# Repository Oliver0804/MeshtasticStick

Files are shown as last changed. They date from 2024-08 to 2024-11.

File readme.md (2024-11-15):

# MeshtasticStick
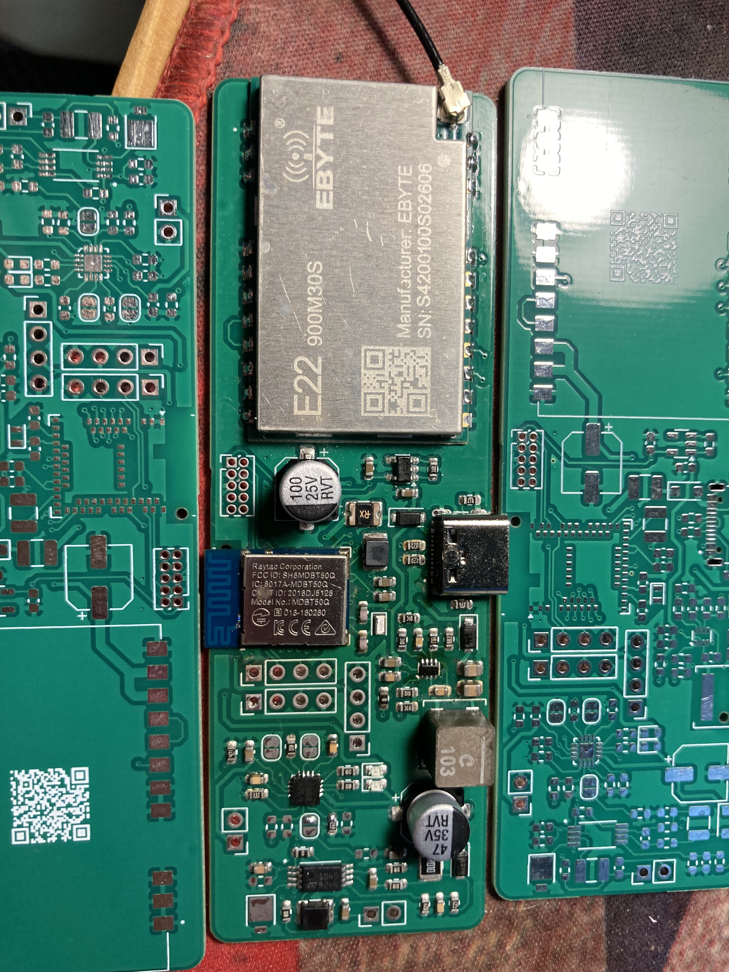
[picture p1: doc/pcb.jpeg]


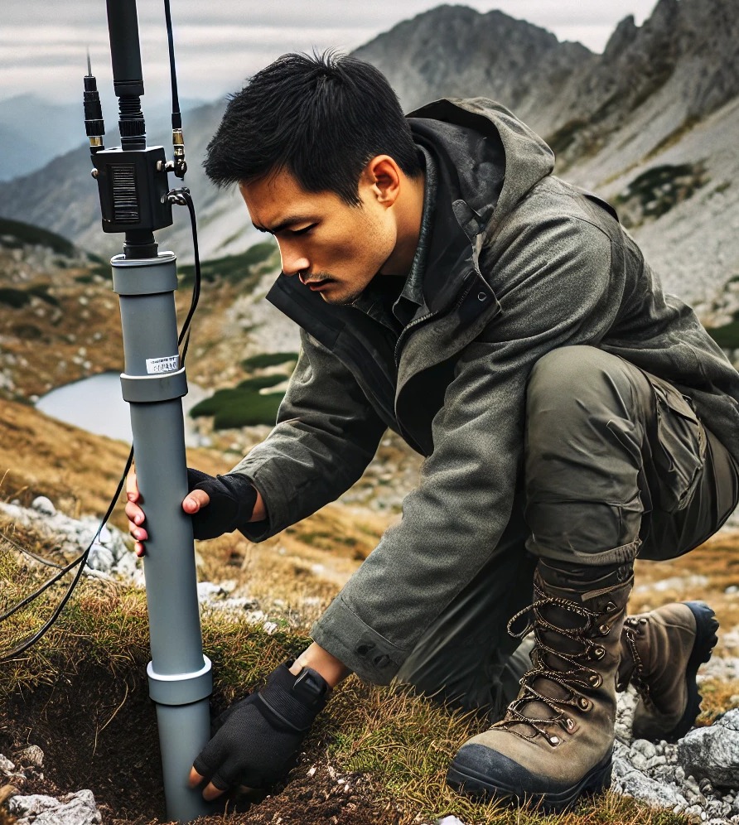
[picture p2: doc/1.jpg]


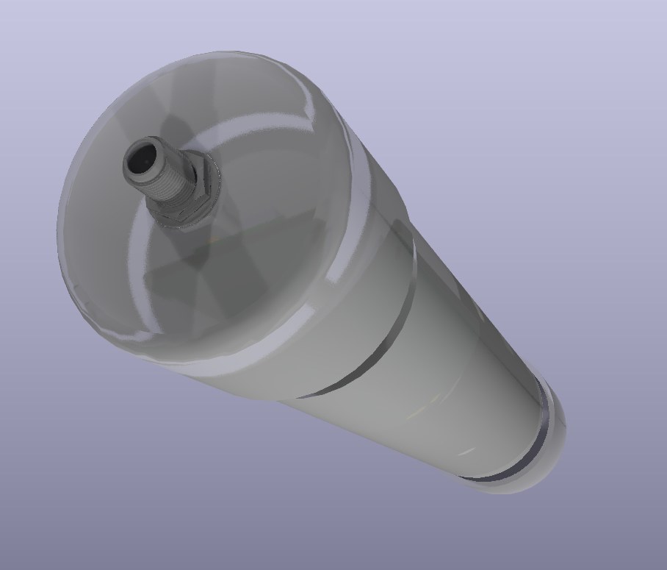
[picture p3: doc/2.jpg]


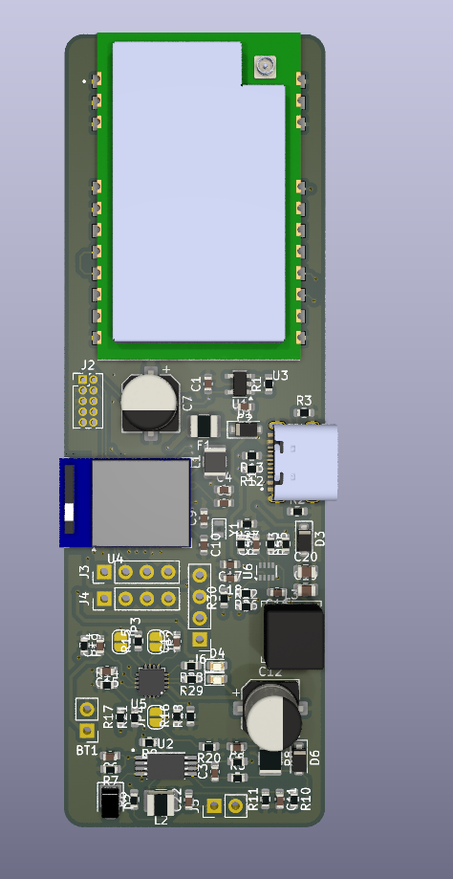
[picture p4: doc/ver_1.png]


1. 支持太陽能（0.3V~5.5V）
2. 支持寬壓輸入（4.5V~28V）
3. TypeC 供電(輸入最少5V/1.5A)，如無充電狀況下約0.8A
4. NRF52 不支持WI-FI
5. 預留I2C,GPS接口(GPS可使用Jumper切換電壓3v3/5v0)

# 原理圖
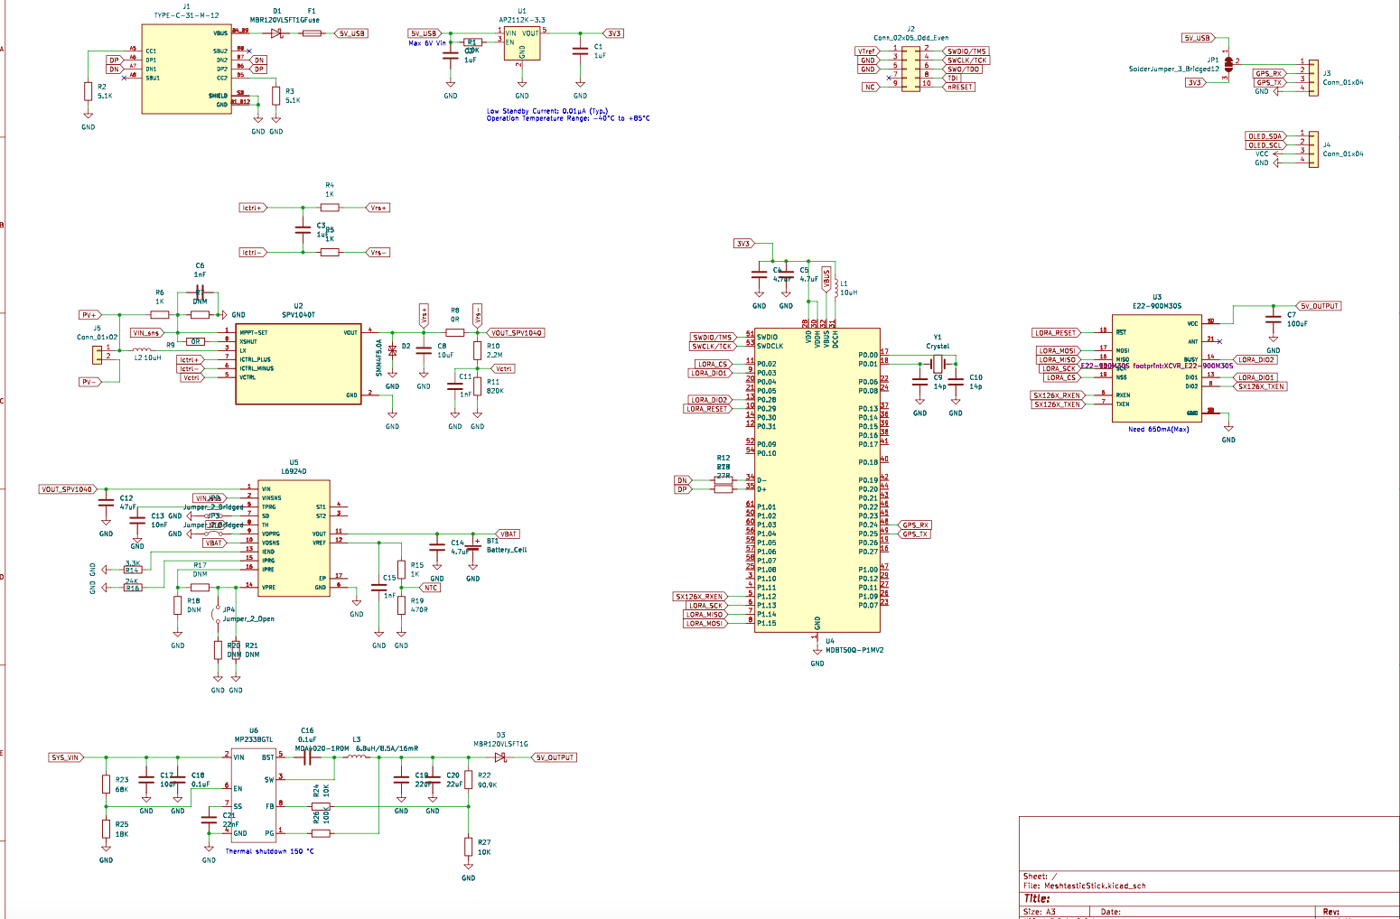
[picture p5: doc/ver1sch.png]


# 主要零件
1. MDBT50Q-P1MV2
描述: 這是由Raytac Corporation生產的一款BLE模塊，基於Nordic Semiconductor的nRF52840晶片。此模塊支持Bluetooth 5.1規範，具有低功耗藍牙(BLE)功能。
優勢: 具有較大的傳輸範圍、高數據傳輸速率和低能耗。支持多種無線通訊協議，包括藍牙、ANT和2.4 GHz射頻。此外，內建32位ARM Cortex-M4 CPU，具有豐富的GPIO和接口，適合複雜的物聯網(IoT)應用。

2. SPV1040（voltage range from 0.3 V to 5.5 V）
描述: SPV1040是STMicroelectronics的一款高效率太陽能充電控制器，適用於低功耗應用和可攜式太陽能系統。
優勢: 能夠在廣泛的太陽照射條件下有效提高能量收集效率，支持最大功率點追蹤(MPPT)技術，以最大化太陽能板的能量輸出。此IC具有過載保護和熱保護功能，能確保系統的穩定與安全。

3. L6924 (取代LT4056系列)
描述: L6924是一款用於單節鋰離子或鋰聚合物電池的充電管理IC，由STMicroelectronics製造。
優勢: 這個充電器支持調整充電電流和電壓，以適應不同電池的需求。它包括內部功率晶體管和電流感測功能，無需外部許多元件，非常適合便攜式設備。

4. MP2338 (4.5V to 28V Operating Input Range)
描述: MP2338是由MPS公司生產的一款同步降壓轉換器，用於將更高的電壓轉換為更低的電壓，同時提供高效率和優異的負載調節。
優勢: 它具有高達95%的轉換效率，非常適合需要高效能轉換的應用。此外，其具有緊湊的尺寸和低靜態功耗，非常適合電池供電的系統。

5. E22-900M30/33 1W LORA
描述: Ebyte製造的E22-900M30/33是一款高功率LoRa模塊，工作在900 MHz頻段，提供長距離無線通信。
優勢: 此模塊的最大發射功率達到1瓦特，能夠實現極遠的通信距離。支持LoRa和FSK調制，具有良好的抗干擾性能和低功耗特性。此外，模塊的配置靈活，支持多種工作模式，非常適合需要遠距離數據傳輸的物聯網應用。

# TODO
- [ ] 確認SPV1040工作狀態
- [ ] L6924 ST1,ST2確認設計方式
- [ ] 確認4.2v供電

# ref

- 太陽能設計文件
https://static5.arrow.com/pdfs/2011/10/8/19/12/15/660/st_/auto/steval-isv012v1_schematic.pdf

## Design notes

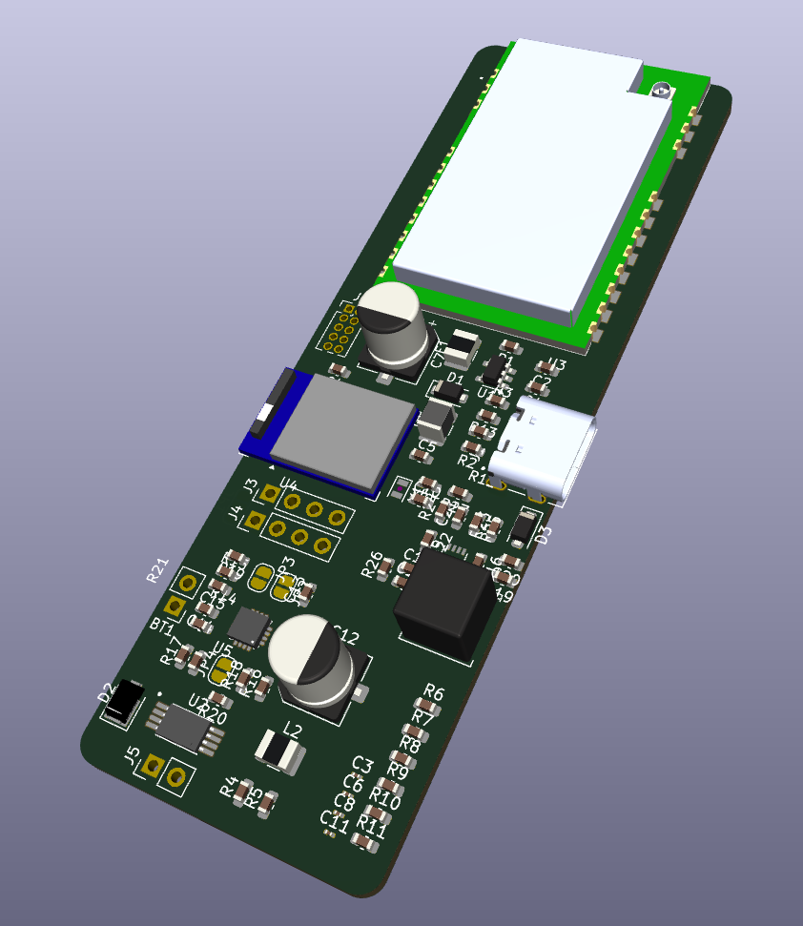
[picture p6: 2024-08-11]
doc/ver13d.png

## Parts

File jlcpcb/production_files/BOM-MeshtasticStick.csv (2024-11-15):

Comment | Designator | Footprint | LCSC | Quantity
68K | R23 | R_0603_1608Metric | C12036 | 1
0.1uF | C16,C18,C6 | C_0603_1608Metric | C14663 | 3
1uF | C1,C2,C3 | C_0603_1608Metric | C15849 | 3
1nF | C11,C15 | C_0603_1608Metric | C1588 | 2
100K | R26 | R_0603_1608Metric | C17900 | 1
4.7uF | C14,C4,C5 | C_0603_1608Metric | C19666 | 3
10uF | C17,C22,C8 | C_0603_1608Metric | C19702 | 3
SMM4F5.0A | D2 | D_SMP_DO-220AA | C1976670 | 1
Fuse | F1 | Fuse_1210_3225Metric | C20806 | 1
22nF | C21 | C_0603_1608Metric | C21122 | 1
0R | R30,R9 | R_0603_1608Metric | C21189 | 2
1K | R15,R28,R29,R4,R5,R6 | R_0603_1608Metric | C21190 | 6
MBR120VLSFT1G | D1,D3,D6 | D_SOD-123F | C223608 | 3
LED | D4,D5 | LED_0603_1608Metric | C2286 | 2
2.2M | R10 | R_0603_1608Metric | C22938 | 1
3.3K | R14 | R_0603_1608Metric | C22978 | 1
90.9K | R22 | R_0603_1608Metric | C23129 | 1
470R | R19 | R_0603_1608Metric | C23179 | 1
5.1K | R2,R3 | R_0603_1608Metric | C23186 | 2
820K | R11 | R_0603_1608Metric | C23252 | 1
24K | R16 | R_0603_1608Metric | C23352 | 1
27R | R12,R13 | R_0603_1608Metric | C25190 | 2
10K | R1,R24,R27 | R_0603_1608Metric | C25804 | 3
18K | R25 | R_0603_1608Metric | C25810 | 1
AP2112K-3.3 | U1 | SOT-23-5 | C3021085 | 1
100uF | C7 | CP_Elec_6.3x7.7 | C3338 | 1
47uF | C12 | CP_Elec_6.3x7.7 | C3344 | 1
14p | C10,C9 | C_0603_1608Metric | C38523 | 2
22uF | C19,C20 | C_0805_2012Metric | C45783 | 2
10nF | C13 | C_0603_1608Metric | C57112 | 1
MP2338GTL | U6 | SOT-583-8 | C7210174 | 1
10uH | L1,L2 | L_1210_3225Metric | C86073 | 2
Crystal | Y1 | Crystal_SMD_2012-2Pin_2.0x1.2mm | C90943 | 1
TYPE-C-31-M-12 | J1 | HRO_TYPE-C-31-M-12 |  | 1
DNM | R20 | R_0603_1608Metric |  | 1
MDA4020-1R0M 6.8uH/8.5A/16mR | L3 | L_Coilcraft_XAL6060-XXX |  | 1
10mR | R8 | R_1210_3225Metric |  | 1
Conn_01x04 | J4 | PinHeader_1x04_P2.54mm_Vertical |  | 1
Conn_02x05_Odd_Even | J2 | PinHeader_2x05_P1.27mm_Vertical |  | 1
DNM | R18 | R_0603_1608Metric |  | 1
DNM | R21 | R_0603_1608Metric |  | 1
L6924D | U5 | QFN50P300X300X100-17N |  | 1
E22-900M30S | U3 | XCVR_E22-900M30S |  | 1
DNM | R17 | R_0603_1608Metric |  | 1
Conn_01x04 | J3 | PinHeader_1x04_P2.54mm_Vertical |  | 1
SPV1040T | U2 | SOP65P640X120-8N |  | 1
Jumper_2_Bridged | JP2 | SolderJumper-2_P1.3mm_Bridged2Bar_RoundedPad1.0x1.5mm |  | 1
Conn_01x04 | J6 | PinHeader_1x04_P2.54mm_Vertical |  | 1
Jumper_2_Bridged | JP3 | SolderJumper-2_P1.3mm_Bridged2Bar_RoundedPad1.0x1.5mm |  | 1
Conn_01x02 | J5 | PinHeader_1x02_P2.54mm_Vertical |  | 1
MDBT50Q-P1MV2 | U4 | Raytac_MDBT50Q |  | 1
Battery_Cell | BT1 | PinHeader_1x02_P2.54mm_Vertical |  | 1
Jumper_2_Open | JP4 | SolderJumper-2_P1.3mm_Open_RoundedPad1.0x1.5mm |  | 1
DNM | R7 | R_0603_1608Metric |  | 1

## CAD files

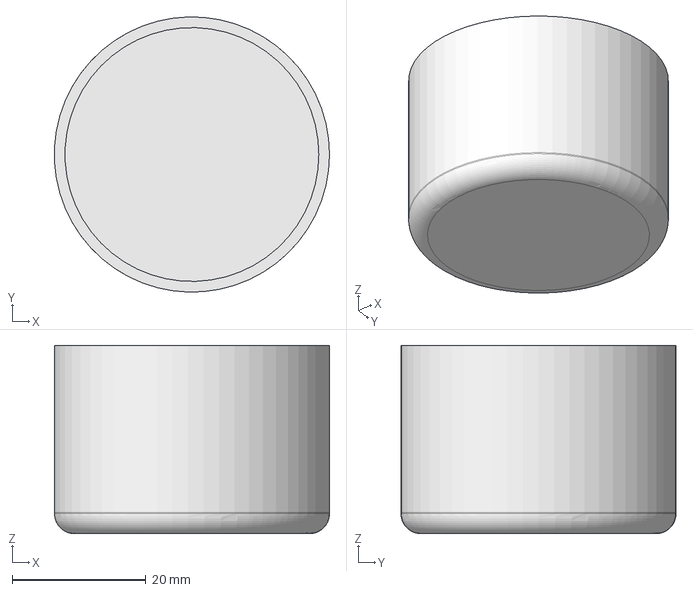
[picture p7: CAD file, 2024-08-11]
Case-PVC蓋子.step
41.2 x 41.2 x 28.2 mm

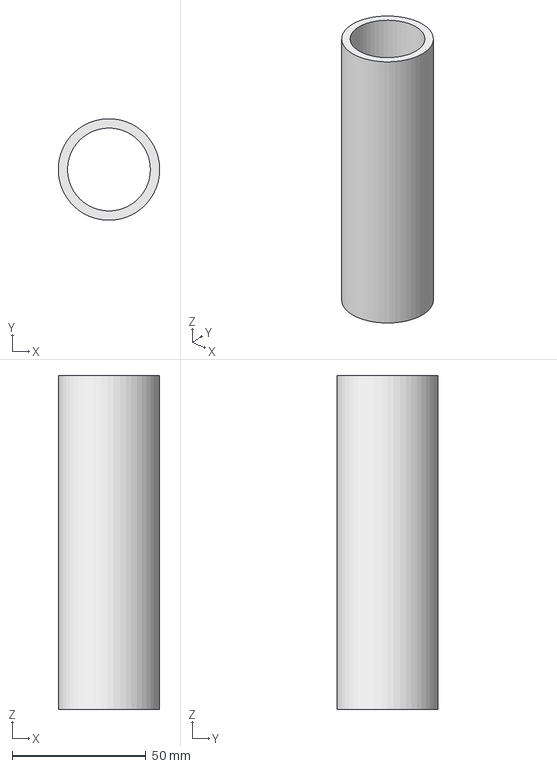
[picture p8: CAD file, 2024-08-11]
Case-PVC.step
38.0 x 38.0 x 125.0 mm

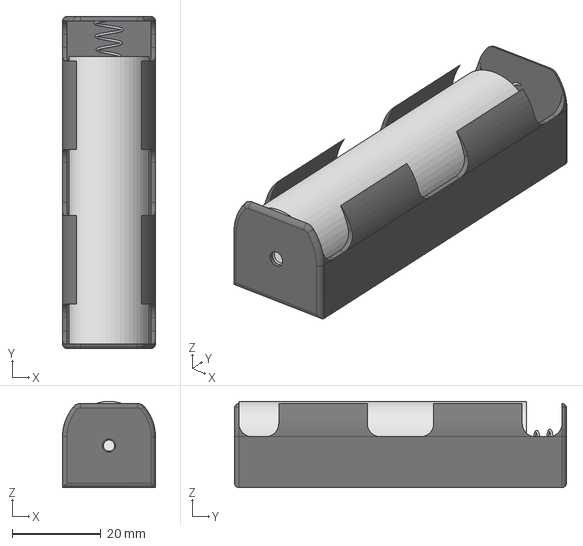
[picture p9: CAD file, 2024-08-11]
18650 Battery Holder v5.step
21.0 x 75.0 x 19.5 mm

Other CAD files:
Case.FCStd

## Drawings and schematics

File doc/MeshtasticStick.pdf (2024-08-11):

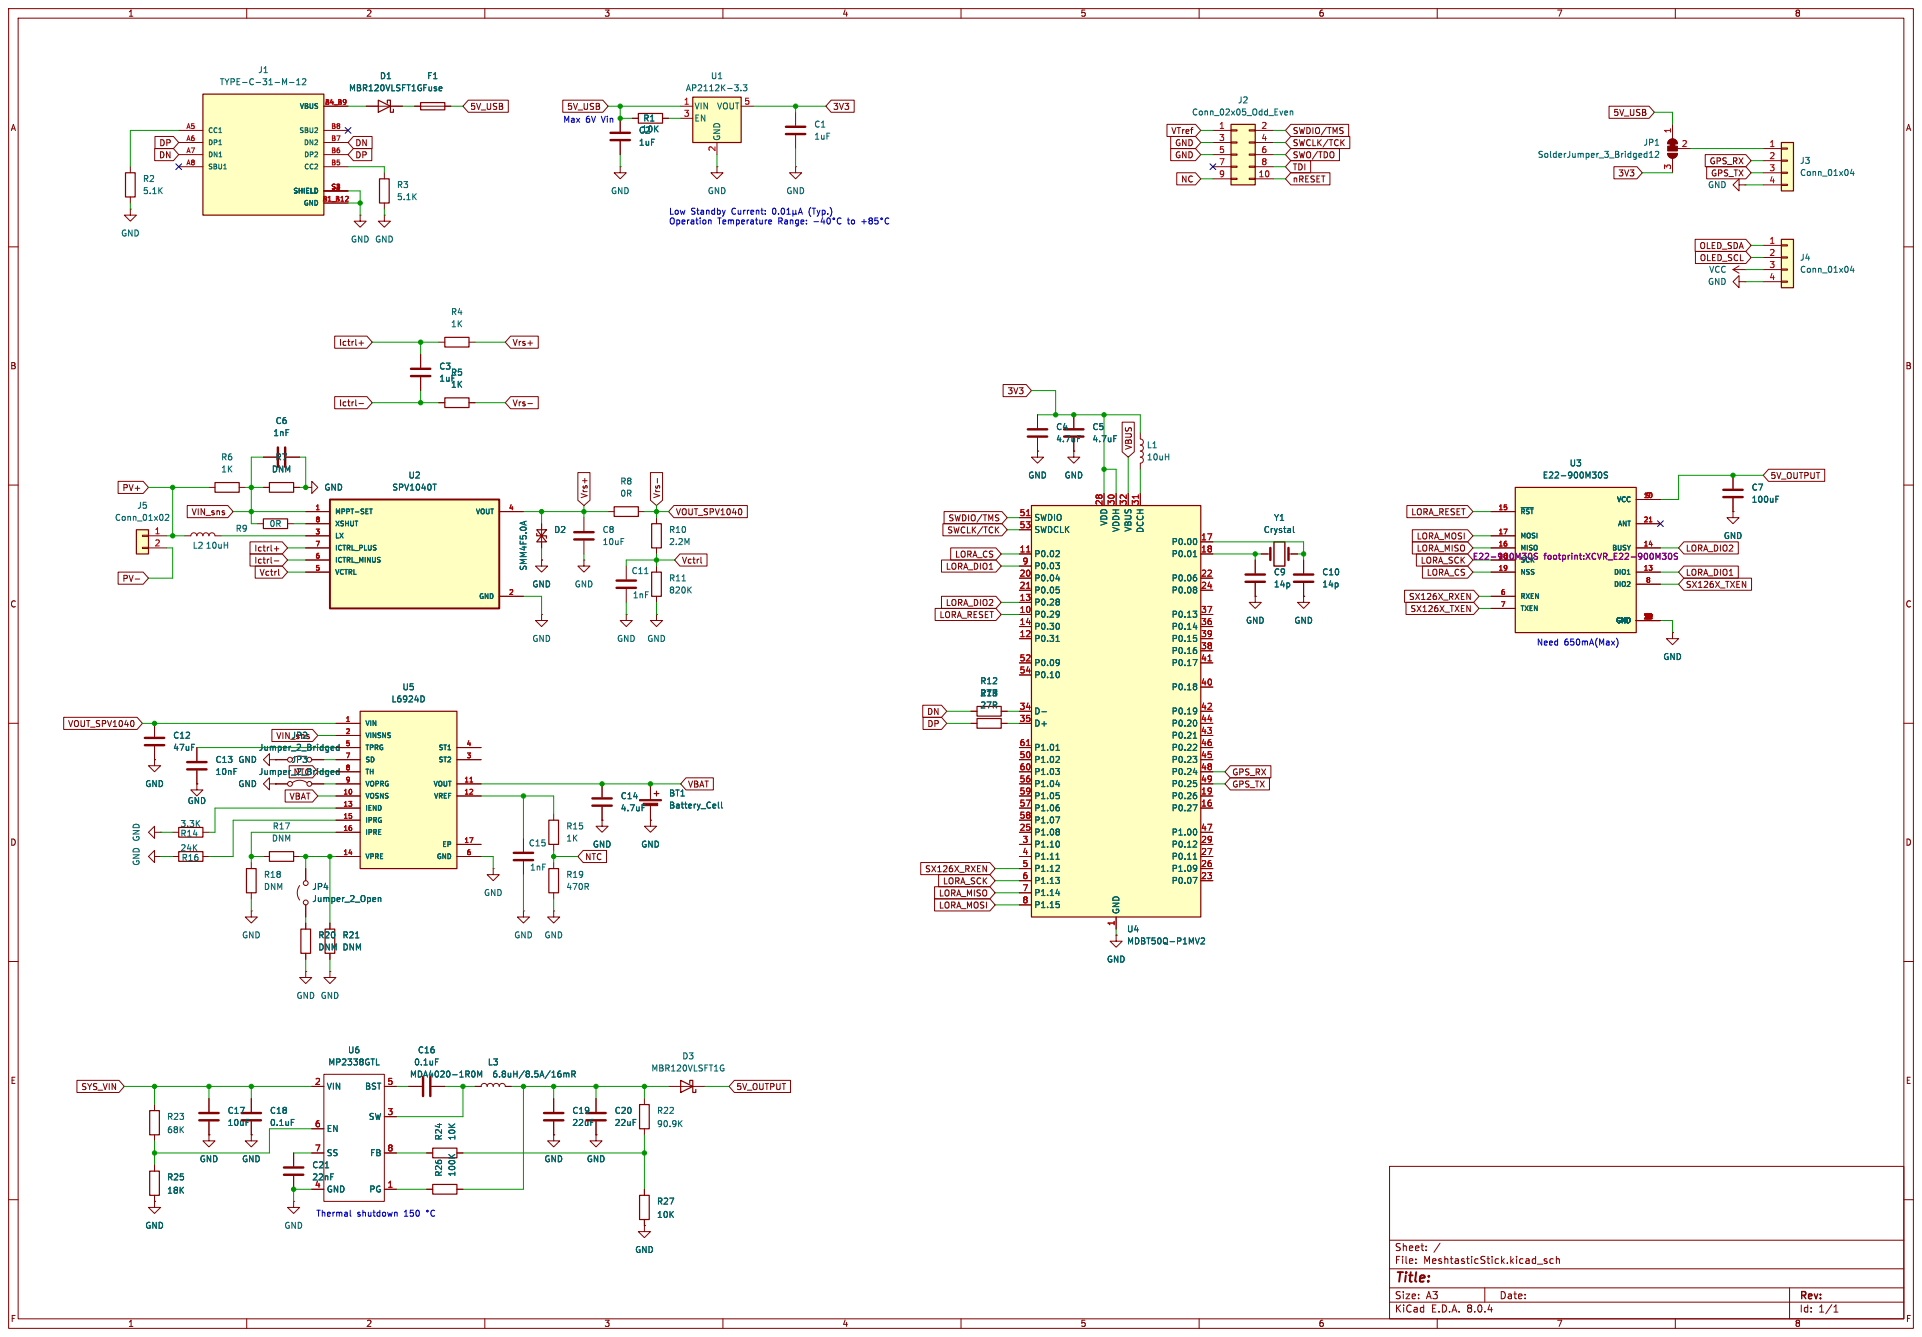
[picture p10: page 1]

Low Standby Current: þÿ0.01µA(Typ.)

1 P0.29 10 P0.02 11 P0.31 12 P0.28 13 P0.30 14 P0.27 16 P0.00 17 P0.01 18 P0.26 19 P0.04 20 P0.05 21 P0.06 22 P0.07 23 P0.08 24 P1.08 25 P1.09 26 P0.11 27 VDD 28 P0.12 29 P1.10 3 VDDH 30 DCCH 31 VBUS 32 D- 34 D+ 35 P0.14 36 P0.13 37 P0.16 38 P0.15 39 P1.11 4 P0.18 40 P0.17 41 P0.19 42 P0.21 43 P0.20 44 P0.23 45 P0.22 46 P1.00 47 P0.24 48 P0.25 49 P1.12 5 P1.02 50 SWDIO 51 P0.09 52 SWDCLK 53 P0.10 54 P1.04 56 P1.06 57 P1.07 58 P1.05 59 P1.13 6 P1.03 60 P1.01 61 P1.14 7 P1.15 8 P0.03 9 U4 MDBT50Q-P1MV2 GND

1 P0.29 10 P0.02 11 P0.31 12 P0.28 13 P0.30 14 P0.27 16 P0.00 17 P0.01 18 P0.26 19 P0.04 20 P0.05 21 P0.06 22 P0.07 23 P0.08 24 P1.08 25 P1.09 26 P0.11 27 VDD 28 P0.12 29 P1.10 3 VDDH 30 DCCH 31 VBUS 32 D- 34 D+ 35 P0.14 36 P0.13 37 P0.16 38 P0.15 39 P1.11 4 P0.18 40 P0.17 41 P0.19 42 P0.21 43 P0.20 44 P0.23 45 P0.22 46 P1.00 47 P0.24 48 P0.25 49 P1.12 5 P1.02 50 SWDIO 51 P0.09 52 SWDCLK 53 P0.10 54 P1.04 56 P1.06 57 P1.07 58 P1.05 59 P1.13 6 P1.03 60 P1.01 61 P1.14 7 P1.15 8 P0.03 9 GND

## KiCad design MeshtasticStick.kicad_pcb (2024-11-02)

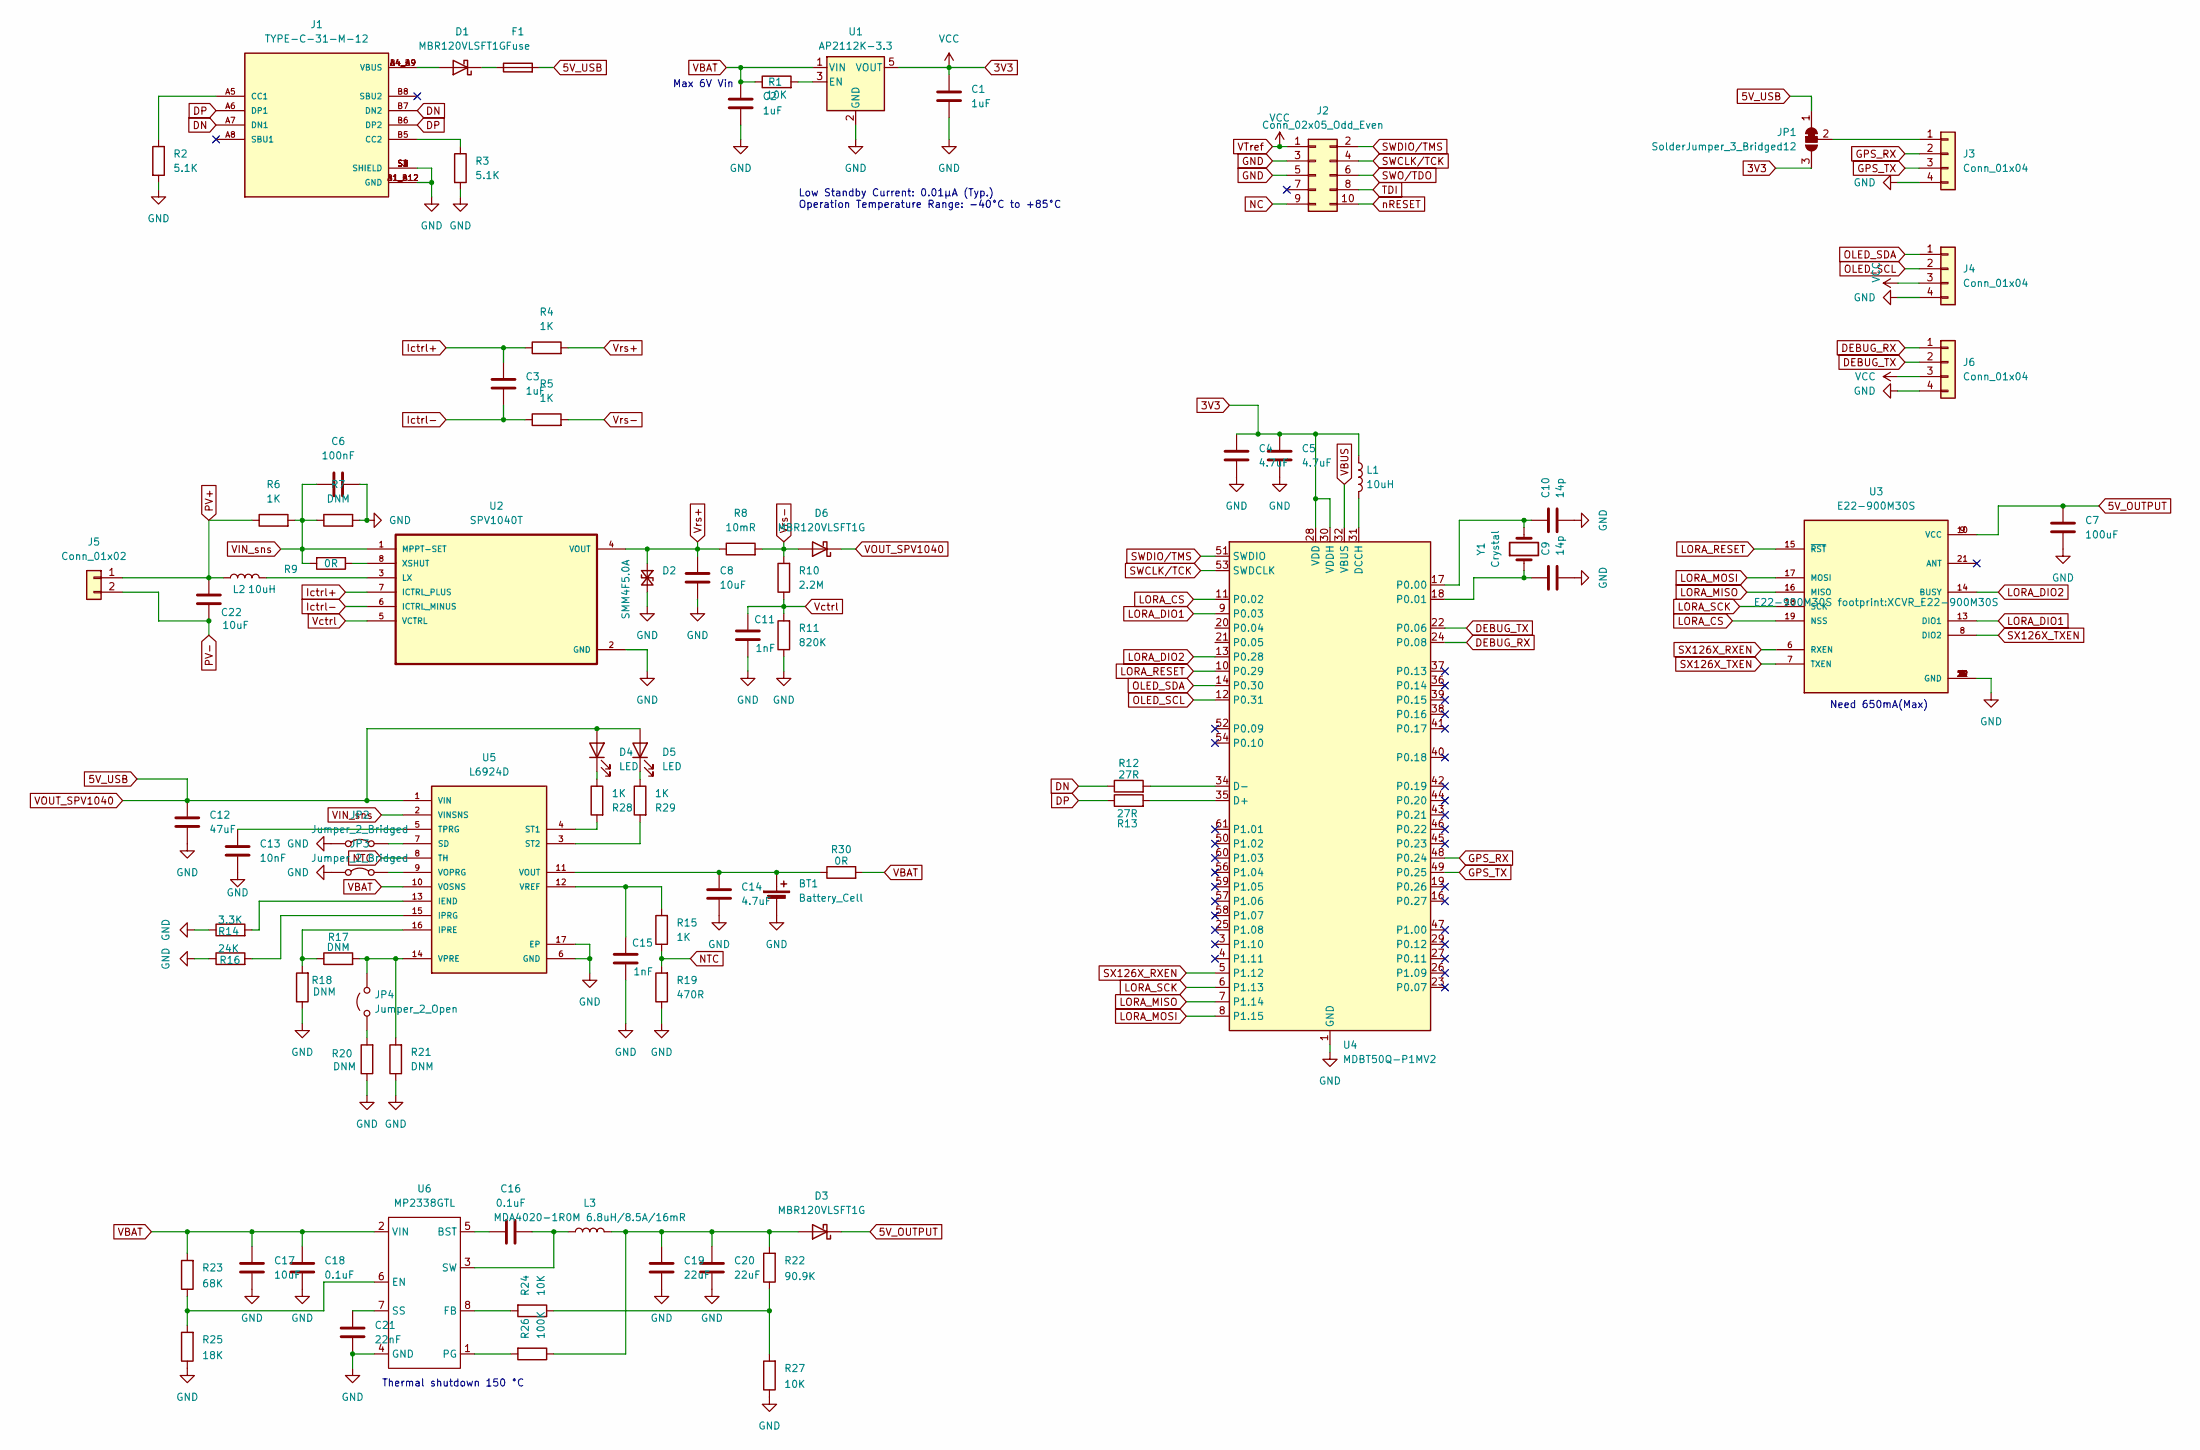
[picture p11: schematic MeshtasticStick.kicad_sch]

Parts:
BT1: Battery_Cell; PinHeader_1x02_P2.54mm_Vertical
C1, C2, C3: 1uF; C_0603_1608Metric
C4, C5, C14: 4.7uF; C_0603_1608Metric
C6: 100nF; C_0603_1608Metric
C7: 100uF; CP_Elec_6.3x7.7
C8, C17, C22: 10uF; C_0603_1608Metric
C9, C10: 14p; C_0603_1608Metric
C11, C15: 1nF; C_0603_1608Metric
C12: 47uF; CP_Elec_6.3x7.7
C13: 10nF; C_0603_1608Metric
C16, C18: 0.1uF; C_0603_1608Metric
C19, C20: 22uF; C_0805_2012Metric
C21: 22nF; C_0603_1608Metric
D1, D3, D6: MBR120VLSFT1G; D_SOD-123F
D2: SMM4F5.0A; D_SMP_DO-220AA
D4, D5: LED; LED_0603_1608Metric
F1: Fuse; Fuse_1210_3225Metric
J1: TYPE-C-31-M-12; HRO_TYPE-C-31-M-12; PARTREV 2020.12.08
J2: Conn_02x05_Odd_Even; PinHeader_2x05_P1.27mm_Vertical
J3, J4, J6: Conn_01x04; PinHeader_1x04_P2.54mm_Vertical
J5: Conn_01x02; PinHeader_1x02_P2.54mm_Vertical
JP1: SolderJumper_3_Bridged12; SolderJumper-3_P1.3mm_Open_RoundedPad1.0x1.5mm
JP2, JP3: Jumper_2_Bridged; SolderJumper-2_P1.3mm_Bridged2Bar_RoundedPad1.0x1.5mm
JP4: Jumper_2_Open; SolderJumper-2_P1.3mm_Open_RoundedPad1.0x1.5mm
L1: 10uH; L_1210_3225Metric
L2: 10uH; Fuse_1210_3225Metric
L3: MDA4020-1R0M 6.8uH/8.5A/16mR; L_Coilcraft_XAL6060-XXX
R1, R24, R27: 10K; R_0603_1608Metric
R2, R3: 5.1K; R_0603_1608Metric
R4, R5, R6, R15, R28, R29: 1K; R_0603_1608Metric
R7, R17, R18, R20, R21: DNM; R_0603_1608Metric
R8: 10mR; R_1210_3225Metric
R9, R30: 0R; R_0603_1608Metric
R10: 2.2M; R_0603_1608Metric
R11: 820K; R_0603_1608Metric
R12, R13: 27R; R_0603_1608Metric
R14: 3.3K; R_0603_1608Metric
R16: 24K; R_0603_1608Metric
R19: 470R; R_0603_1608Metric
R22: 90.9K; R_0603_1608Metric
R23: 68K; R_0603_1608Metric
R25: 18K; R_0603_1608Metric
R26: 100K; R_0603_1608Metric
U1: AP2112K-3.3; SOT-23-5
U2: SPV1040T; SOP65P640X120-8N; PARTREV 7
U3: E22-900M30S; XCVR_E22-900M30S; PARTREV 1.2
U4: MDBT50Q-P1MV2; Raytac_MDBT50Q
U5: L6924D; QFN50P300X300X100-17N
U6: MP2338GTL; SOT-583-8
Y1: Crystal; Crystal_SMD_2012-2Pin_2.0x1.2mm

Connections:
3V3: C1.1, C4.1, C5.1, J2.1, J4.3, J6.3, JP1.3 (B), L1.1, U1.5 (VOUT), U4.28 (VDD), U4.30 (VDDH)
5V_OUTPUT: C7.1, D3.1 (K), U3.9 (VCC), U3.10 (VCC)
5V_USB: C12.1, D4.2 (A), D5.2 (A), D6.1 (K), F1.2, JP1.1 (A), U5.1 (VIN)
DEBUG_RX: J6.1, U4.24 (P0.08)
DEBUG_TX: J6.2, U4.22 (P0.06)
DN: J1.A7 (DN1), J1.B7 (DN2), R12.1
DP: J1.A6 (DP1), J1.B6 (DP2), R13.1
GND: BT1.2 (-), C1.2, C2.2, C4.2, C5.2, C6.2, C7.2, C8.2, C9.2, C10.2, C11.2, C12.2, C13.2, C14.2, C15.2, C17.2, C18.2, C19.2, C20.2, C21.2, D2.2 (A2), J1.A1_B12 (GND), J1.B1_A12 (GND), J1.S1 (SHIELD), J1.S2 (SHIELD), J1.S3 (SHIELD), J1.S4 (SHIELD), J2.3, J2.5, J3.4, J4.4, J6.4, JP2.1 (A), JP3.1 (A), R2.2, R3.2, R7.2, R11.1, R14.1, R16.1, R18.1, R19.1, R20.1, R21.1, R25.1, R27.1, U1.2 (GND), U2.2 (GND), U3.1 (GND), U3.2 (GND), U3.3 (GND), U3.4 (GND), U3.5 (GND), U3.11 (GND), U3.12 (GND), U3.20 (GND), U3.22 (GND), U4.1 (GND), U4.2 (GND), U4.15 (GND), U4.33 (GND), U4.55 (GND), U5.6 (GND), U5.17 (EP), U6.4 (GND)
GPS_RX: J3.2, U4.48 (P0.24)
GPS_TX: J3.3, U4.49 (P0.25)
Ictrl+: C3.2, R4.1, U2.7 (ICTRL_PLUS)
Ictrl-: C3.1, R5.1, U2.6 (ICTRL_MINUS)
LORA_CS: U3.19 (NSS), U4.11 (P0.02)
LORA_DIO1: U3.13 (DIO1), U4.9 (P0.03)
LORA_DIO2: U3.14 (BUSY), U4.13 (P0.28)
LORA_MISO: U3.16 (MISO), U4.7 (P1.14)
LORA_MOSI: U3.17 (MOSI), U4.8 (P1.15)
LORA_RESET: U3.15 (~RST), U4.10 (P0.29)
LORA_SCK: U3.18 (SCK), U4.6 (P1.13)
NC: J2.9
NTC: R15.1, R19.2, U5.8 (TH)
unnamed: BT1.1 (+), C14.1, R30.1, U5.11 (VOUT)
unnamed: D1.2 (A), J1.A4_B9 (VBUS), J1.B4_A9 (VBUS)
unnamed: D1.1 (K), F1.1
unnamed: C19.1, C20.1, D3.2 (A), L3.2, R22.2, R26.1
unnamed: D4.1 (K), R28.1
unnamed: D5.1 (K), R29.1
unnamed: J1.A5 (CC1), R2.1
unnamed: J1.B5 (CC2), R3.1
unnamed: J3.1, JP1.2 (C)
unnamed: JP2.2 (B), U5.7 (SD)
unnamed: JP3.2 (B), U5.9 (VOPRG)
unnamed: JP4.1 (A), R20.2
unnamed: JP4.2 (B), R17.2, R21.2, U5.14 (VPRE)
unnamed: R22.1, R24.1, R27.2
unnamed: R1.2, U1.3 (EN)
unnamed: L2.2, U2.3 (LX)
unnamed: R9.1, U2.8 (XSHUT)
unnamed: R13.2, U4.35 (D+)
unnamed: R12.2, U4.34 (D-)
unnamed: L1.2, U4.31 (DCCH)
unnamed: C10.1, U4.17 (P0.00), Y1.2
unnamed: C9.1, U4.18 (P0.01), Y1.1
unnamed: R14.2, U5.13 (IEND)
unnamed: R17.1, R18.2, U5.16 (IPRE)
unnamed: R16.2, U5.15 (IPRG)
unnamed: R28.2, U5.4 (ST1)
unnamed: R29.2, U5.3 (ST2)
unnamed: C13.1, U5.5 (TPRG)
unnamed: C15.1, R15.2, U5.12 (VREF)
unnamed: C16.1, U6.5 (BST)
unnamed: R23.1, R25.2, U6.6 (EN)
unnamed: R24.2, U6.8 (FB)
unnamed: R26.2, U6.1 (PG)
unnamed: C21.1, U6.7 (SS)
unnamed: C16.2, L3.1, U6.3 (SW)
OLED_SCL: J4.2, U4.12 (P0.31)
OLED_SDA: J4.1, U4.14 (P0.30)
PV+: C22.1, J5.1, L2.1, R6.1
PV-: C22.2, J5.2
SWCLK/TCK: J2.4, U4.53 (SWDCLK)
SWDIO/TMS: J2.2, U4.51 (SWDIO)
SWO/TDO: J2.6
SX126X_RXEN: U3.6 (RXEN), U4.5 (P1.12)
SX126X_TXEN: U3.7 (TXEN), U3.8 (DIO2)
TDI: J2.8
VBAT: C2.1, C17.1, C18.1, R1.1, R23.2, R30.2, U1.1 (VIN), U5.10 (VOSNS), U6.2 (VIN)
VBUS: U4.32 (VBUS)
VIN_sns: C6.1, R6.2, R7.1, R9.2, U2.1 (MPPT-SET), U5.2 (VINSNS)
Vctrl: C11.1, R10.1, R11.2, U2.5 (VCTRL)
Vrs+: C8.1, D2.1 (A1), R4.2, R8.1, U2.4 (VOUT)
Vrs-: D6.2 (A), R5.2, R8.2, R10.2
nRESET: J2.10

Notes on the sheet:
Need 650mA(Max)
Thermal shutdown 150 °C
Max 6V Vin
Low Standby Current: 0.01µA (Typ.) Operation Temperature Range: -40°C to +85°C

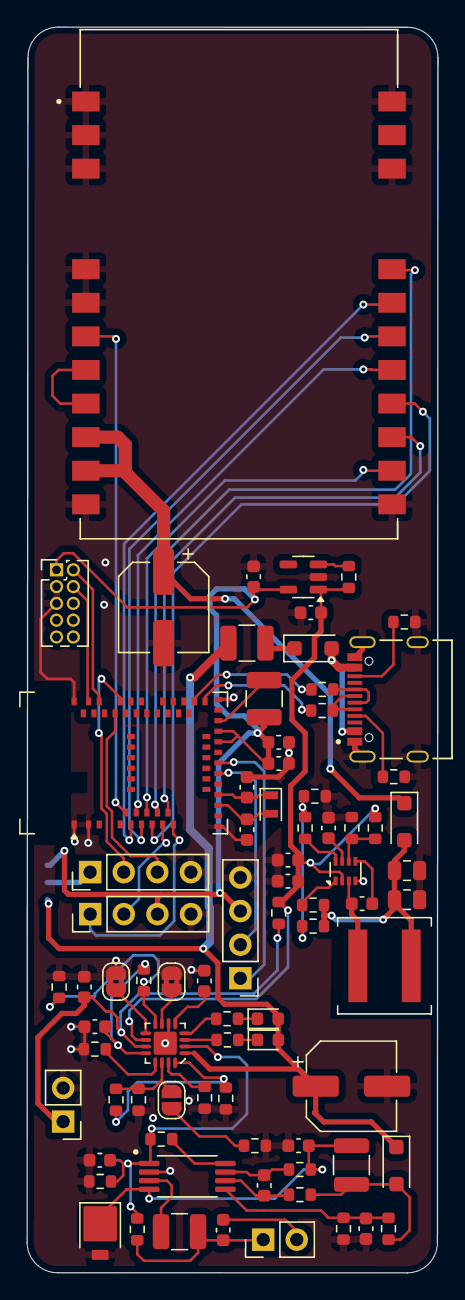
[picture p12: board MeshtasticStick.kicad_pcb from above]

Board: 2 copper layers, 31.1 x 94.2 mm, 80 parts (1 on the bottom side), 68 nets.

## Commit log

2024-11-02 [fix] Fix power supply issue and capacitor packaging, complete initial routing
    - Fixed power supply issue to improve stability
    - Adjusted certain capacitor packages to meet design requirements
    - Completed initial PCB routing
    - Corrected OLED signal routing to ensure proper display
    [MeshtasticStick.kicad_pcb, MeshtasticStick.kicad_sch]
2024-11-15 添加貼片完成照片
    [BOM-MeshtasticStick.csv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]
